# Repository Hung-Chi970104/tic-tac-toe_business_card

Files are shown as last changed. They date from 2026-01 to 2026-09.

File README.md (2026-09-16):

# Tic-Tac-Toe Business Card

**A playable RP2040 business card with a printed NFC antenna and a minimax computer opponent.**

[PCB layout](#pcb-layout) · [NFC design](#passive-nfc-and-antenna) · [Demos](#see-it-work) · [Schematic](#schematic) · [Design files](#design-files)

## PCB layout

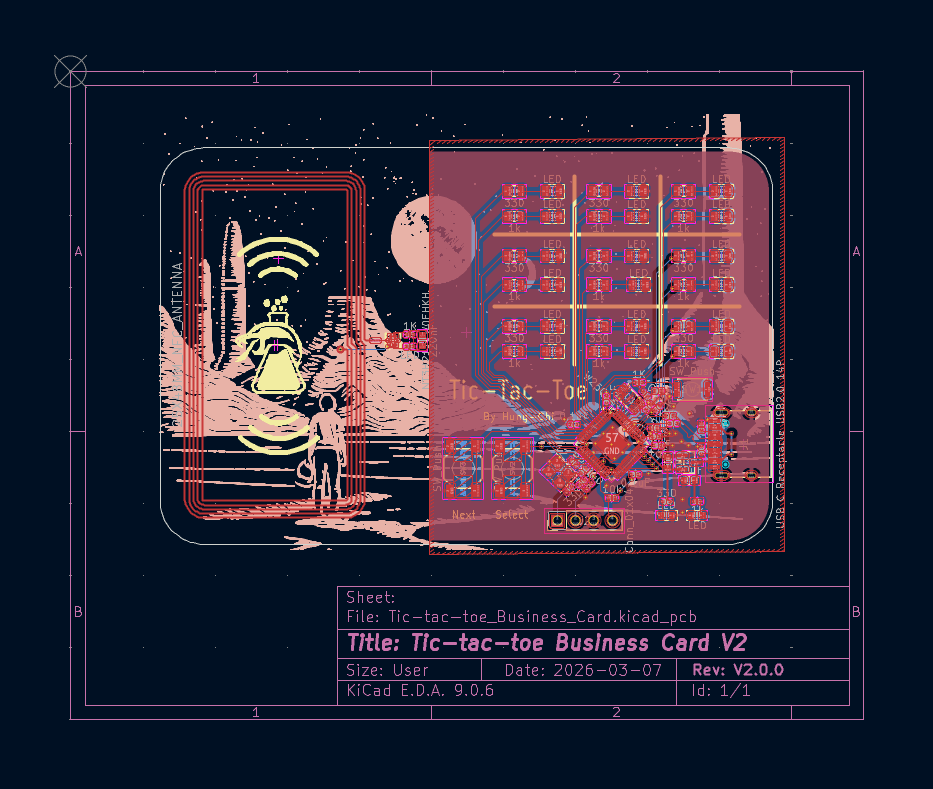
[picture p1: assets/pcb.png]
Routed business-card PCB showing the copper NFC coil, nine game cells and RP2040 circuitry


The layout combines a large copper-coil NFC antenna with the game interface and embedded electronics. The **18 game LEDs form nine dual-colour cells**, giving each player one indicator per square; Next and Select buttons provide the controls.

## What I built

- Designed the RP2040 board, LED interface, USB-C connection and passive NFC circuit.
- Integrated a **25 × 48 mm PCB copper-coil antenna** with an **NT3H2111 NFC tag**.
- Implemented two-player gameplay and a **minimax opponent with alpha-beta pruning**, which skips search branches that cannot improve the chosen move.
- Completed two PCB revisions, resolving the initial NFC fault and demonstrating both gameplay and tap-to-open linking.

## Passive NFC and antenna

The coil is part of the PCB copper, connected to the NFC tag's antenna terminals. A compatible phone supplies the field needed for passive **13.56 MHz** NFC reading, so the portfolio link can be read **without USB power**. Gameplay uses the powered RP2040 and LED circuit.

The grid uses 18 LEDs; three additional indicators sit outside the nine game cells.

## See it work

| Demonstration | Watch |
|---|---|
| Two-player game | [Gameplay video](https://youtube.com/shorts/xTpW4rk7Zjw) |
| Computer opponent | [Minimax gameplay](https://youtu.be/wkJYNbXEyfI) |
| Passive NFC | [Phone tap → portfolio link](https://youtube.com/shorts/Xky8sBx_JWE) |

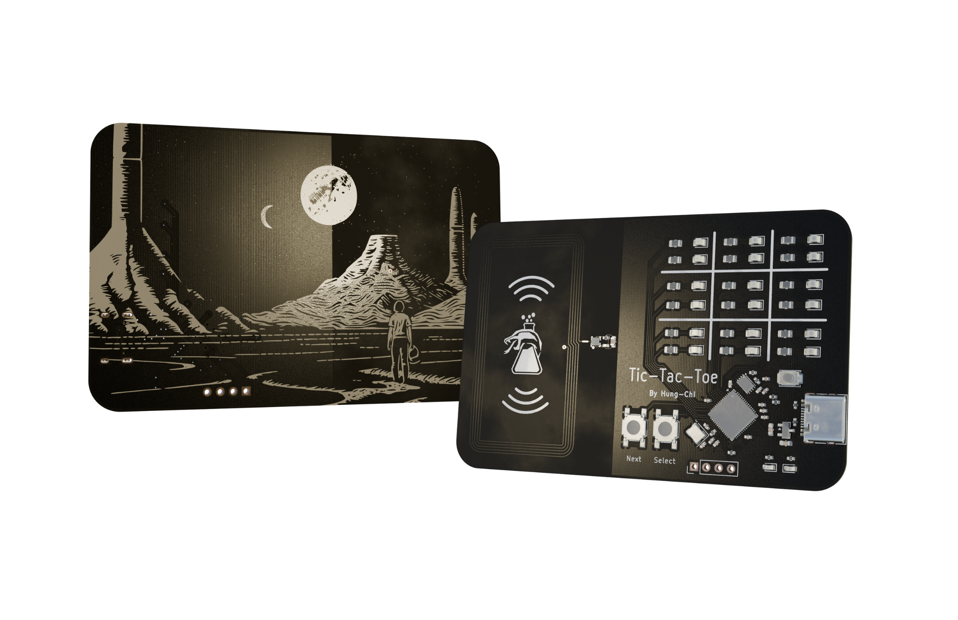
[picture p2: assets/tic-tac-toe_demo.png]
Original project demonstration image (https://youtu.be/wkJYNbXEyfI)


## Schematic

[Full-resolution schematic](assets/schematic.svg) · [KiCad schematic](Tic-tac-toe_Business_Card.kicad_sch)

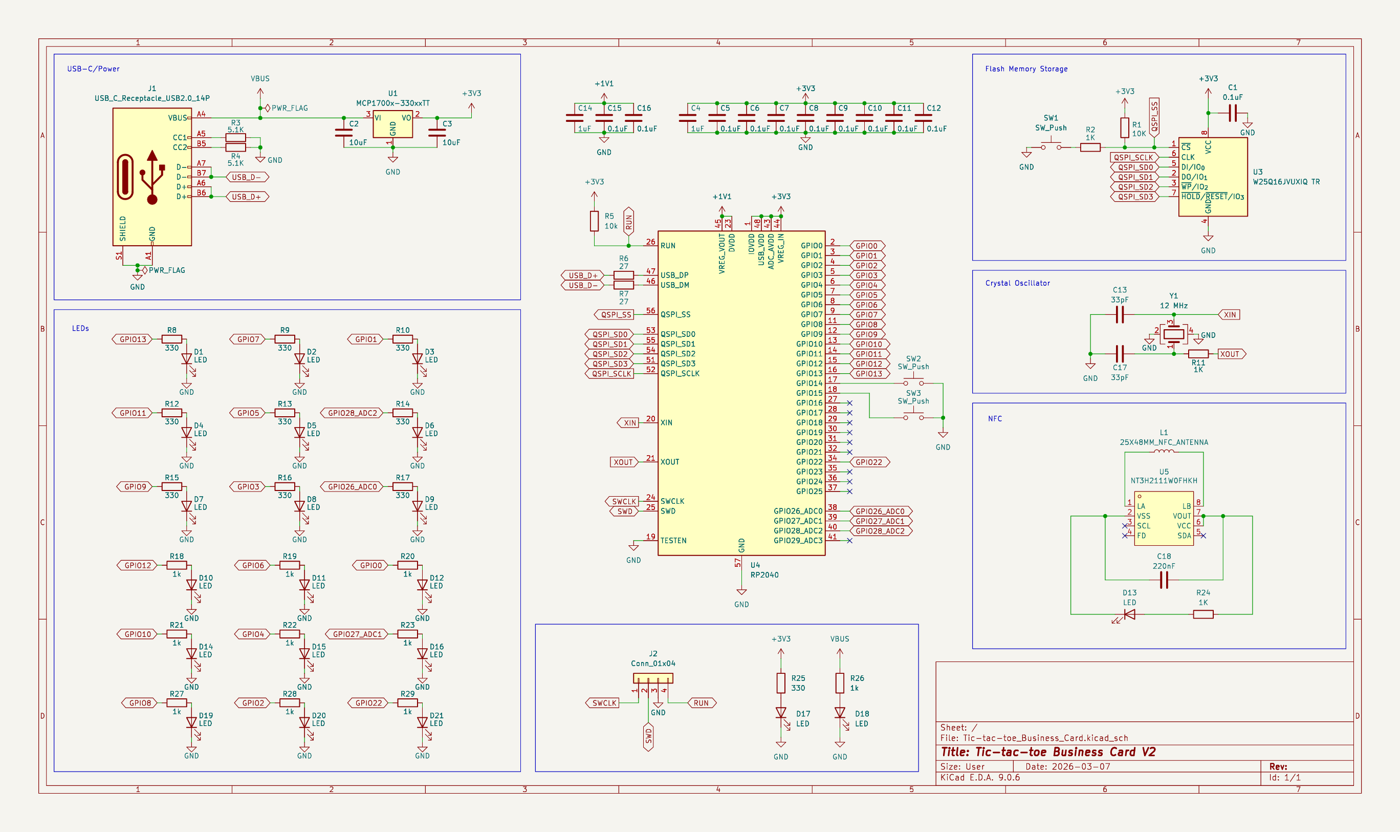
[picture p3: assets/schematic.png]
Schematic of the RP2040, game LEDs, controls and NFC circuitry


## 3D views

Original board renders:

| Front | Back |
|---|---|
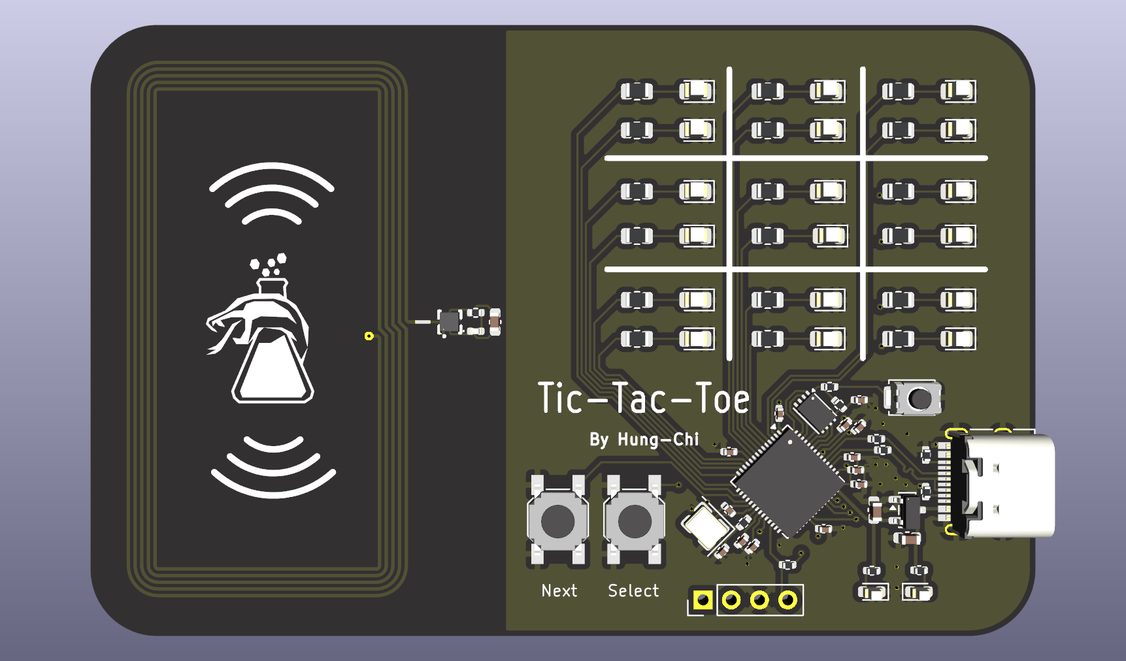
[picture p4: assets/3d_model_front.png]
Original front 3D view
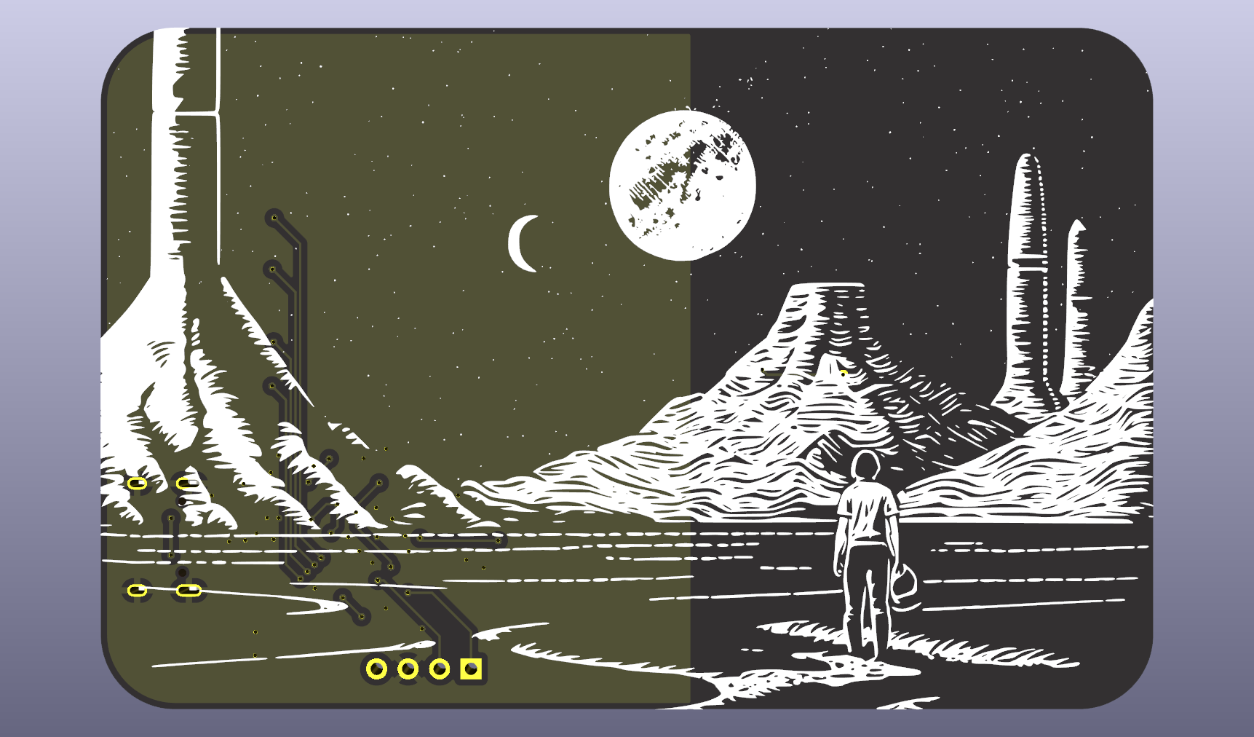
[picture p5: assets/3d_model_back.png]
Original back 3D view
|  |  |

## Design files

| Resource | Link |
|---|---|
| KiCad project | [Project file](Tic-tac-toe_Business_Card.kicad_pro) |
| Routed board | [PCB source](Tic-tac-toe_Business_Card.kicad_pcb) |
| Copper layers | [Front](assets/Tic-tac-toe_Business_Card-F_Cu.svg) · [Back](assets/Tic-tac-toe_Business_Card-B_Cu.svg) |
| NFC footprint | [25 × 48 mm antenna source](lib/NFC_Tic_Tac_Toe.pretty/25X48MM_NFC_ANTENNA.kicad_mod) |
| Manufacturing exports | [Production files](production/) |

The repository contains the hardware design and demonstration assets. The gameplay implementation is demonstrated in the videos; a complete firmware release is not currently included here.

Designed and built by Hung-Chi Wang.

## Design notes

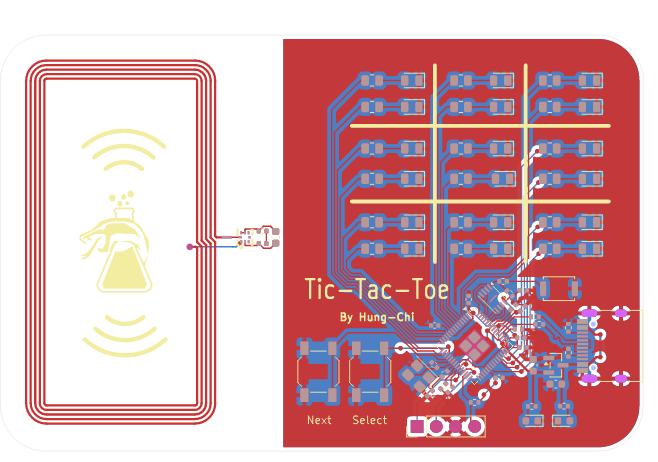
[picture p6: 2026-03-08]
assets/Tic-tac-toe_Business_Card-B_Cu.png

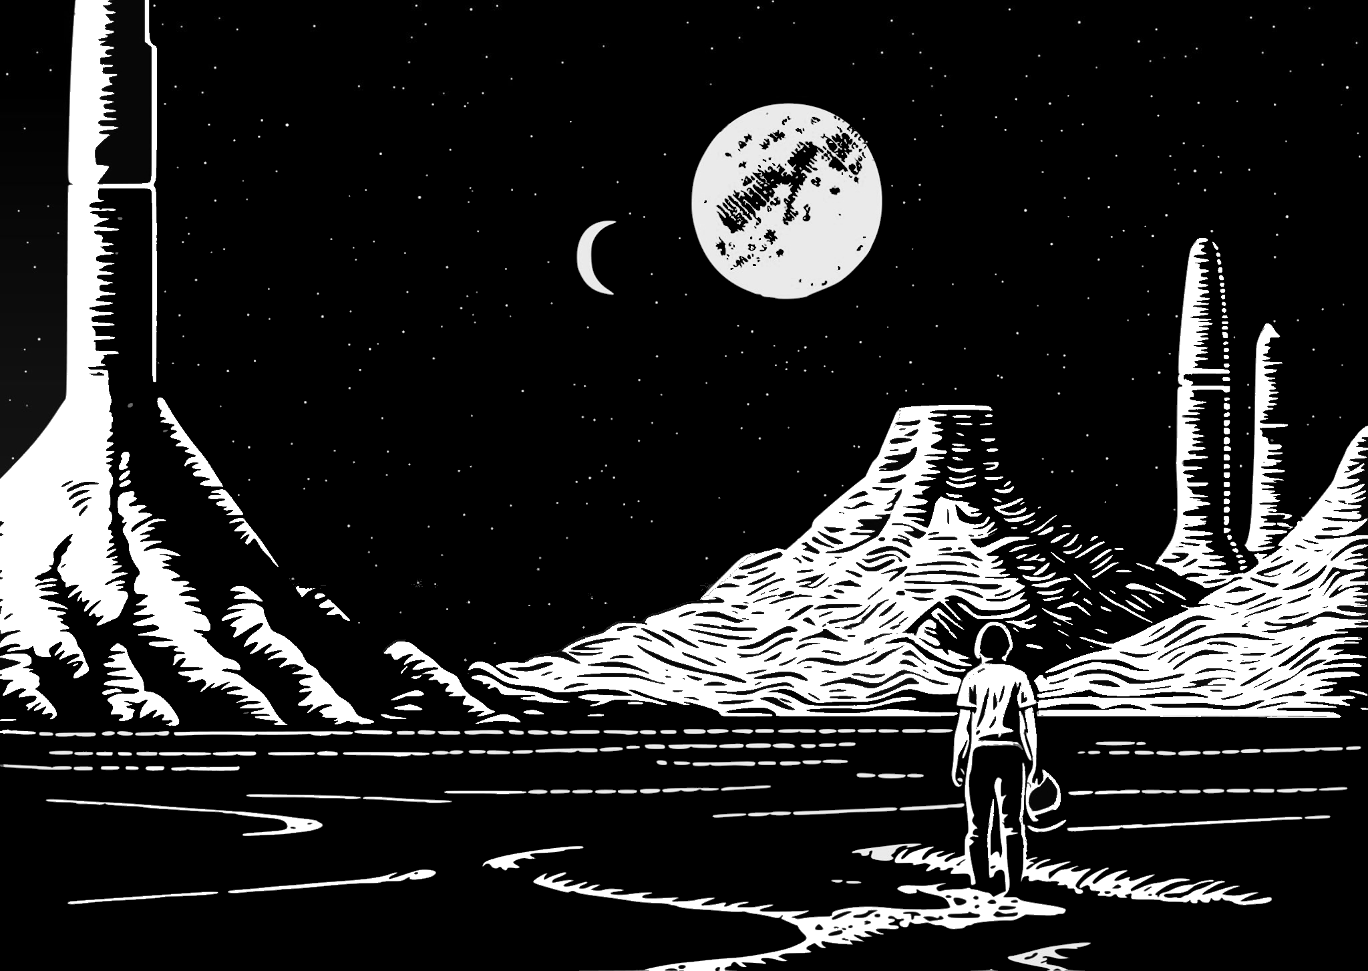
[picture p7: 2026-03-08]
assets/back-image.png

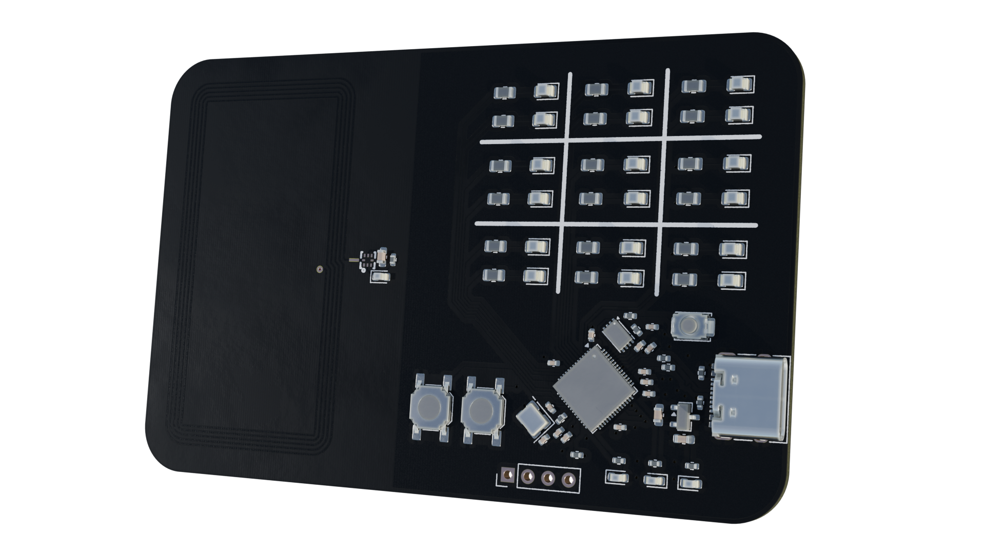
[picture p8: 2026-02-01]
assets/RP2040-tic-tac-toe.png

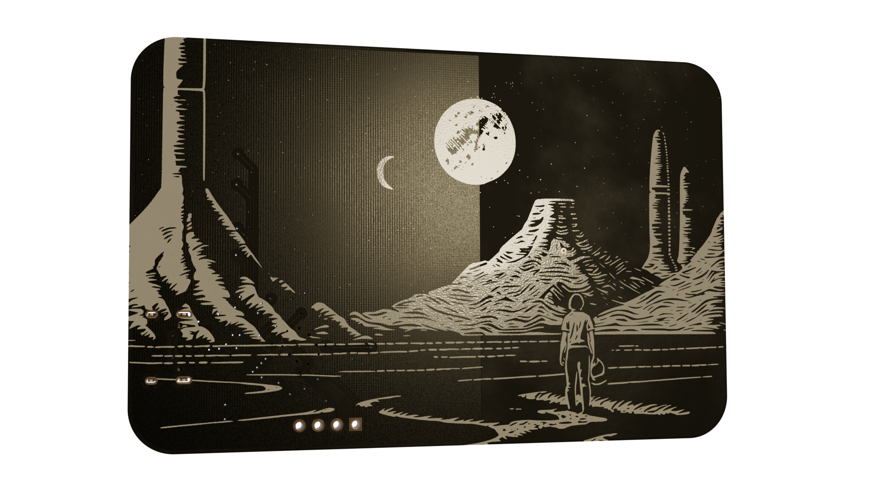
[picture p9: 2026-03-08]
assets/tic-tac-toe_back.png

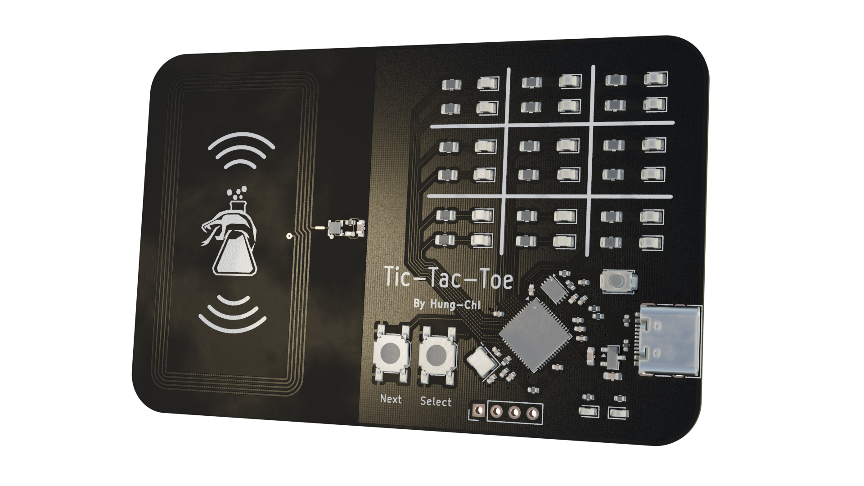
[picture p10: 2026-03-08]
assets/tic_tac_toe_front.png

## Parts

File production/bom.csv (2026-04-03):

Designator | Footprint | Quantity | Value | LCSC Part #
C1, C11, C12, C15, C16, C6, C7, C8, C9 | 0402 | 9 | 0.1uF
C13, C17 | 0402 | 2 | 15pF
C14, C4 | 0402 | 2 | 1uF
C18 | 0603 | 1 | 220nF
C2, C3 | 0603 | 2 | 10uF
D1, D10, D11, D12, D14, D15, D16, D19, D2, D20, D21, D3, D4, D5, D6, D7, D8, D9 | 0805 | 18 | LED
D13 | 0402 | 1 | LED
D17, D18 | 0603 | 2 | LED
J1 | USB_C_Receptacle_HRO_TYPE-C-31-M-12 | 1 | USB_C_Receptacle_USB2.0_14P
J2 | PinHeader_1x04_P2.54mm_Vertical | 1 | Conn_01x04
L1 | 25X48MM_NFC_ANTENNA | 1 | 25X48MM_NFC_ANTENNA
R1, R5 | 0402 | 2 | 10K
R10, R12, R13, R14, R15, R16, R17, R8, R9 | 0805 | 9 | 330
R11, R2, R26, R24 | 0402 | 4 | 1K
R18, R19, R20, R21, R22, R23, R27, R28, R29 | 0805 | 9 | 1k
R25 | 0402 | 1 | 330
R3, R4 | 0402 | 2 | 5.1K
R6, R7 | 0402 | 2 | 27
SW1 | SW_Push_SPST_NO_Alps_SKRK | 1 | SW_Push
SW2, SW3 | SW_SPST_SKQG_WithoutStem | 2 | SW_Push
U1 | SOT-23 | 1 | MCP1700x-330xxTT
U3 | Winbond_USON-8-1EP_3x2mm_P0.5mm_EP0.2x1.6mm | 1 | W25Q16JVUXIQ TR
U4 | QFN-56-1EP_7x7mm_P0.4mm_EP3.2x3.2mm | 1 | RP2040
U5 | XQFN-8_L1.6-W1.6-P0.50-BL_NT3H2111W0FHKH | 1 | NT3H2111W0FHKH | C710403
Y1 | Crystal_SMD_3225-4Pin_3.2x2.5mm | 1 | 12 MHz

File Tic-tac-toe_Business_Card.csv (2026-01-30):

Reference | Qty | Value | DNP | Exclude from BOM | Exclude from Board | Footprint | Datasheet
C1,C2 | 2 | 10uF |  |  |  | Capacitor_SMD:C_0603_1608Metric | ~
C3,C5,C6,C8,C9,C10,C11,C12,C13,C14,C15 | 11 | 0.1uF |  |  |  | Capacitor_SMD:C_0402_1005Metric | ~
C4,C7 | 2 | 1uF |  |  |  | Capacitor_SMD:C_0402_1005Metric | ~
C16,C17 | 2 | 33pF |  |  |  | Capacitor_SMD:C_0402_1005Metric | ~
C18 | 1 | 220nF |  |  |  | Capacitor_SMD:C_0603_1608Metric | ~
D1,D2,D3,D13 | 4 | LED |  |  |  | LED_SMD:LED_0603_1608Metric | ~
D4,D5,D6,D7,D8,D9,D10,D11,D12,D22,D23,D24,D25,D26,D27,D28,D29,D30 | 18 | LED |  |  |  | LED_SMD:LED_0805_2012Metric | ~
J1 | 1 | USB_C_Receptacle_USB2.0_14P |  |  |  | Connector_USB:USB_C_Receptacle_HRO_TYPE-C-31-M-12 | https://www.usb.org/sites/default/files/documents/usb_type-c.zip
J2 | 1 | Conn_01x04 |  |  |  | Connector_PinHeader_2.54mm:PinHeader_1x04_P2.54mm_Vertical | ~
L1 | 1 | 25X48MM_NFC_ANTENNA |  |  |  | NFC_Tic_Tac_Toe:25X48MM_NFC_ANTENNA | ~
R1,R2 | 2 | 5.1K |  |  |  | Resistor_SMD:R_0402_1005Metric | ~
R3 | 1 | 10K |  |  |  | Resistor_SMD:R_0402_1005Metric | ~
R4,R8 | 2 | 1K |  |  |  | Resistor_SMD:R_0402_1005Metric | ~
R5 | 1 | 10k |  |  |  | Resistor_SMD:R_0402_1005Metric | ~
R6,R7 | 2 | 27 |  |  |  | Resistor_SMD:R_0402_1005Metric | ~
R9,R10,R21 | 3 | 330 |  |  |  | Resistor_SMD:R_0402_1005Metric | ~
R11 | 1 | 1k |  |  |  | Resistor_SMD:R_0402_1005Metric | ~
R12,R13,R14,R15,R16,R17,R18,R19,R20 | 9 | 330 |  |  |  | Resistor_SMD:R_0805_2012Metric | ~
R30,R31,R32,R33,R34,R35,R36,R37,R38 | 9 | 1k |  |  |  | Resistor_SMD:R_0805_2012Metric | ~
SW1 | 1 | SW_Push |  |  |  | Button_Switch_SMD:SW_Push_SPST_NO_Alps_SKRK | ~
SW2,SW3 | 2 | SW_Push |  |  |  | Button_Switch_SMD:SW_SPST_SKQG_WithoutStem | ~
U1 | 1 | MCP1700x-330xxTT |  |  |  | Package_TO_SOT_SMD:SOT-23 | http://ww1.microchip.com/downloads/en/DeviceDoc/20001826D.pdf
U2 | 1 | NT3H2111W0FHKH |  |  |  | NFC_Tic_Tac_Toe:XQFN-8_L1.6-W1.6-P0.50-BL_NT3H2111W0FHKH
U3 | 1 | RP2040 |  |  |  | Package_DFN_QFN:QFN-56-1EP_7x7mm_P0.4mm_EP3.2x3.2mm | https://datasheets.raspberrypi.com/rp2040/rp2040-datasheet.pdf
U4 | 1 | W25Q16JVUXIQ TR |  |  |  | Package_SON:Winbond_USON-8-1EP_3x2mm_P0.5mm_EP0.2x1.6mm | https://www.winbond.com/resource-files/w25q128jv_dtr%20revc%2003272018%20plus.pdf
Y1 | 1 | 12 MHz |  |  |  | Crystal:Crystal_SMD_3225-4Pin_3.2x2.5mm | ~

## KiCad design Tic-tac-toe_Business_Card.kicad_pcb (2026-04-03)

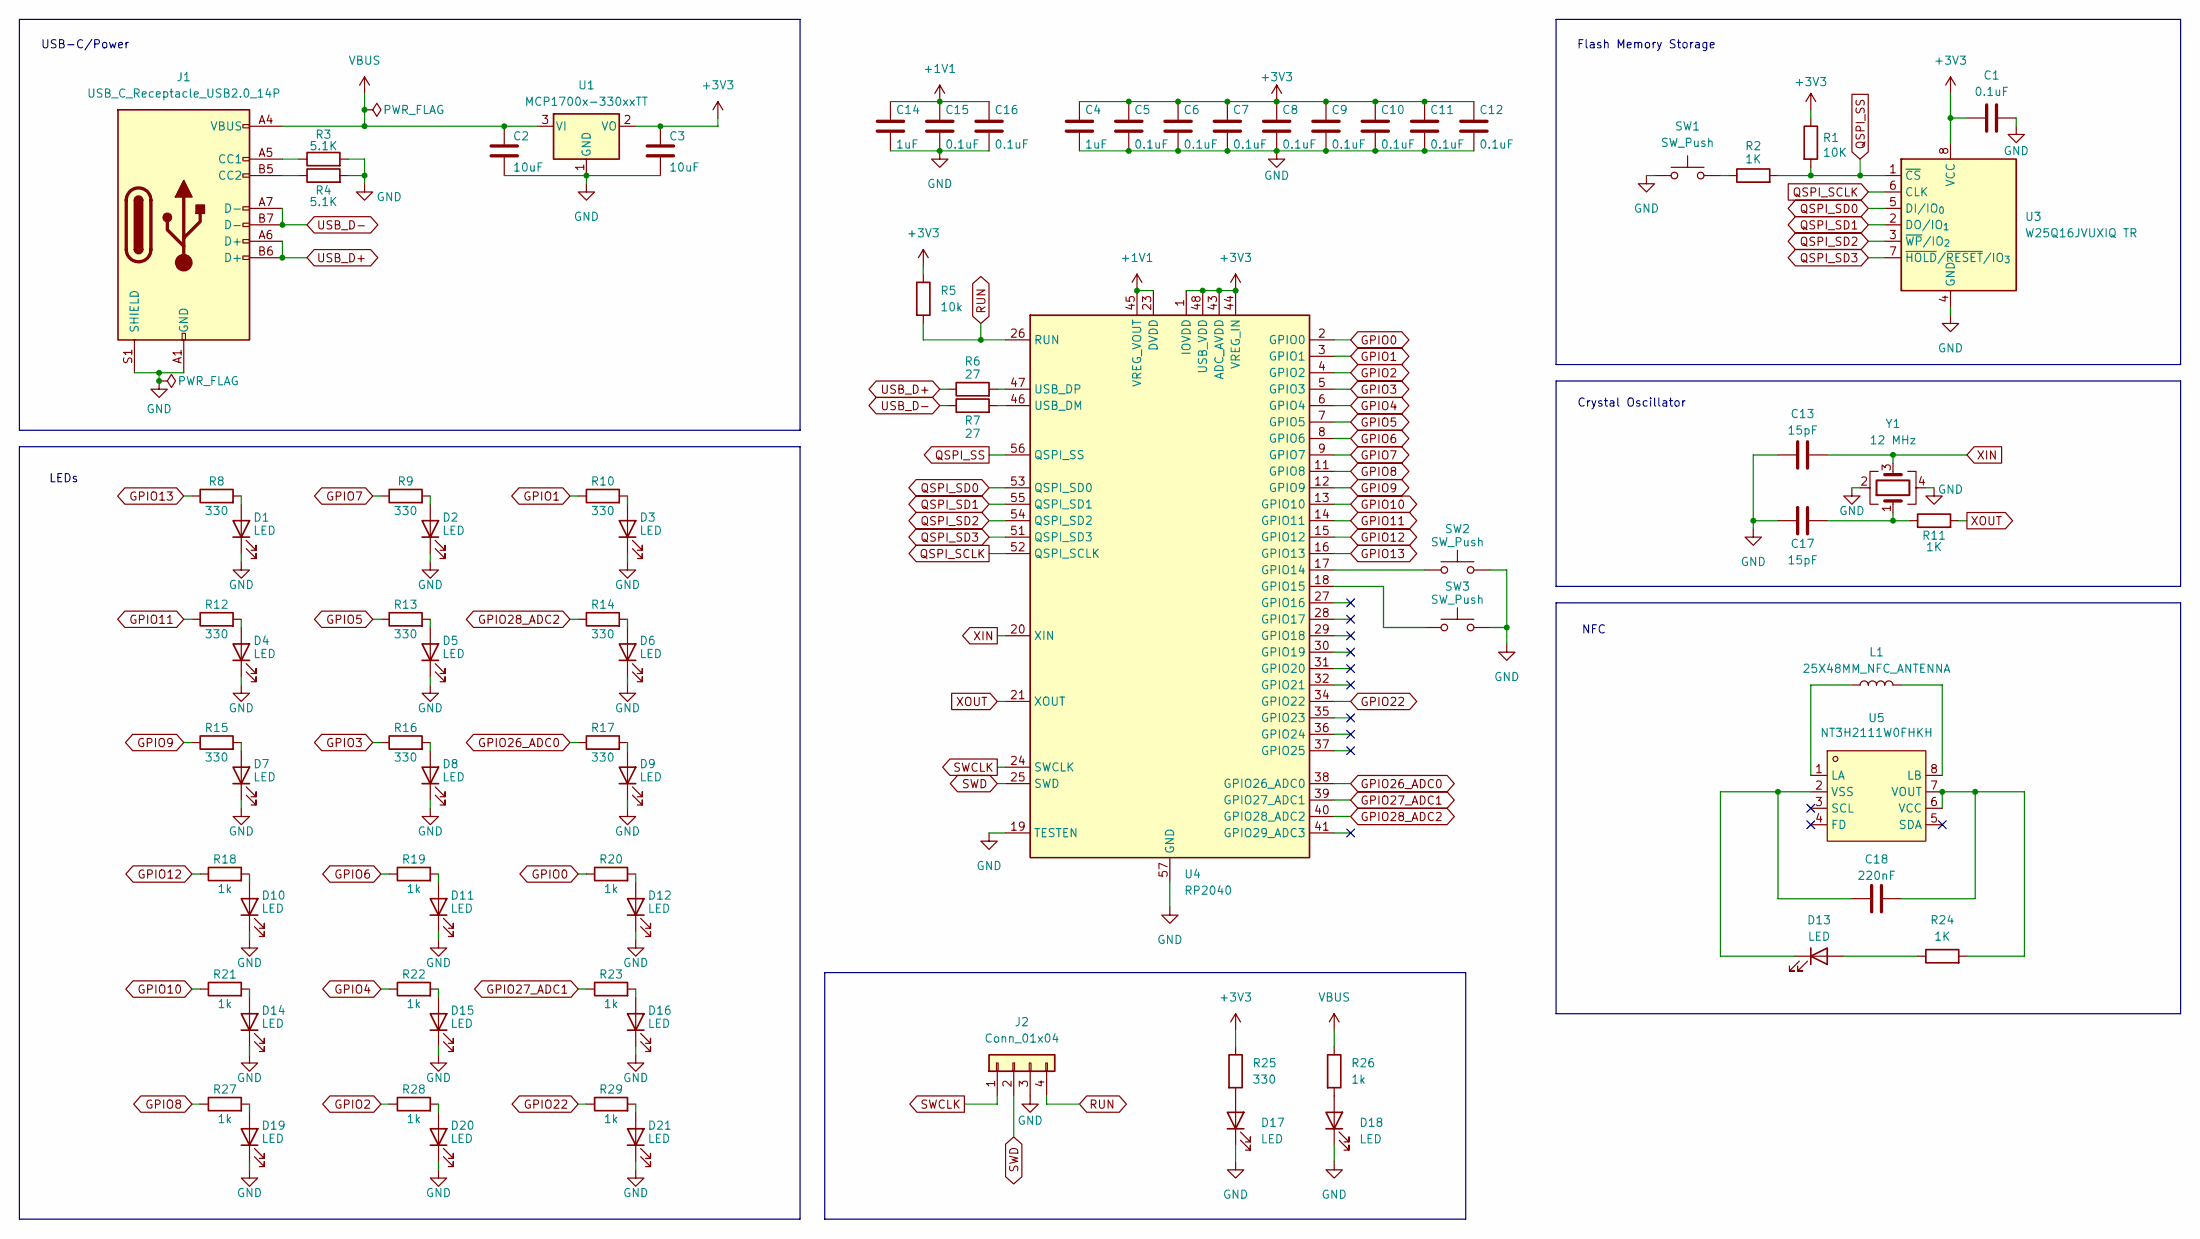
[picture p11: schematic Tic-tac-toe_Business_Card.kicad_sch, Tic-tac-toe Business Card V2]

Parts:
C1, C5, C6, C7, C8, C9, C10, C11, C12, C15, C16: 0.1uF; C_0402_1005Metric
C2, C3: 10uF; C_0603_1608Metric
C4, C14: 1uF; C_0402_1005Metric
C13, C17: 15pF; C_0402_1005Metric
C18: 220nF; C_0603_1608Metric
D1, D2, D3, D4, D5, D6, D7, D8, D9, D10, D11, D12, D14, D15, D16, D19, D20, D21: LED; LED_0805_2012Metric
D13: LED; LED_0402_1005Metric
D17, D18: LED; LED_0603_1608Metric
J1: USB_C_Receptacle_USB2.0_14P; USB_C_Receptacle_HRO_TYPE-C-31-M-12
J2: Conn_01x04; PinHeader_1x04_P2.54mm_Vertical
L1: 25X48MM_NFC_ANTENNA
R1: 10K; R_0402_1005Metric
R2, R11: 1K; R_0402_1005Metric
R3, R4: 5.1K; R_0402_1005Metric
R5: 10k; R_0402_1005Metric
R6, R7: 27; R_0402_1005Metric
R8, R9, R10, R12, R13, R14, R15, R16, R17: 330; R_0805_2012Metric
R18, R19, R20, R21, R22, R23, R27, R28, R29: 1k; R_0805_2012Metric
R24: 1K; R_0402_1005Metric; LCSC C23182
R25: 330; R_0402_1005Metric
R26: 1k; R_0402_1005Metric
SW1: SW_Push; SW_Push_SPST_NO_Alps_SKRK
SW2, SW3: SW_Push; SW_SPST_SKQG_WithoutStem
U1: MCP1700x-330xxTT; SOT-23
U3: W25Q16JVUXIQ TR; Winbond_USON-8-1EP_3x2mm_P0.5mm_EP0.2x1.6mm
U4: RP2040; QFN-56-1EP_7x7mm_P0.4mm_EP3.2x3.2mm
U5: NT3H2111W0FHKH; XQFN-8_L1.6-W1.6-P0.50-BL_NT3H2111W0FHKH; LCSC C710403
Y1: 12 MHz; Crystal_SMD_3225-4Pin_3.2x2.5mm

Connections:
+1V1: C14.1, C15.1, C16.1, U4.23 (DVDD), U4.45 (VREG_VOUT), U4.50 (DVDD)
+3V3: C1.1, C3.1, C4.1, C5.1, C6.1, C7.1, C8.1, C9.1, C10.1, C11.1, C12.1, R1.1, R5.1, R25.1, U1.2 (VO), U3.8 (VCC), U4.1 (IOVDD), U4.10 (IOVDD), U4.22 (IOVDD), U4.33 (IOVDD), U4.42 (IOVDD), U4.43 (ADC_AVDD), U4.44 (VREG_IN), U4.48 (USB_VDD), U4.49 (IOVDD)
GND: C1.2, C2.2, C3.2, C4.2, C5.2, C6.2, C7.2, C8.2, C9.2, C10.2, C11.2, C12.2, C13.1, C14.2, C15.2, C16.2, C17.1, D1.1 (K), D2.1 (K), D3.1 (K), D4.1 (K), D5.1 (K), D6.1 (K), D7.1 (K), D8.1 (K), D9.1 (K), D10.1 (K), D11.1 (K), D12.1 (K), D14.1 (K), D15.1 (K), D16.1 (K), D17.1 (K), D18.1 (K), D19.1 (K), D20.1 (K), D21.1 (K), J1.A1 (GND), J1.A12 (GND), J1.B1 (GND), J1.B12 (GND), J1.S1 (SHIELD), J2.3, R3.2, R4.2, SW1.1, SW2.2, SW3.2, U1.1 (GND), U3.4 (GND), U4.19 (TESTEN), U4.57 (GND), Y1.2, Y1.4
GPIO0: R20.1, U4.2 (GPIO0)
GPIO1: R10.1, U4.3 (GPIO1)
GPIO2: R28.1, U4.4 (GPIO2)
GPIO3: R16.1, U4.5 (GPIO3)
GPIO4: R22.1, U4.6 (GPIO4)
GPIO5: R13.1, U4.7 (GPIO5)
GPIO6: R19.1, U4.8 (GPIO6)
GPIO7: R9.1, U4.9 (GPIO7)
GPIO8: R27.1, U4.11 (GPIO8)
GPIO9: R15.1, U4.12 (GPIO9)
GPIO10: R21.1, U4.13 (GPIO10)
GPIO11: R12.1, U4.14 (GPIO11)
GPIO12: R18.1, U4.15 (GPIO12)
GPIO13: R8.1, U4.16 (GPIO13)
GPIO22: R29.1, U4.34 (GPIO22)
GPIO26_ADC0: R17.1, U4.38 (GPIO26_ADC0)
GPIO27_ADC1: R23.1, U4.39 (GPIO27_ADC1)
GPIO28_ADC2: R14.1, U4.40 (GPIO28_ADC2)
unnamed: C17.2, R11.1, Y1.1
unnamed: D1.2 (A), R8.2
unnamed: D2.2 (A), R9.2
unnamed: D3.2 (A), R10.2
unnamed: D4.2 (A), R12.2
unnamed: D5.2 (A), R13.2
unnamed: D6.2 (A), R14.2
unnamed: D7.2 (A), R15.2
unnamed: D8.2 (A), R16.2
unnamed: D9.2 (A), R17.2
unnamed: D10.2 (A), R18.2
unnamed: D11.2 (A), R19.2
unnamed: D12.2 (A), R20.2
unnamed: D13.2 (A), R24.1
unnamed: C18.1, D13.1 (K), U5.2 (VSS)
unnamed: D14.2 (A), R21.2
unnamed: D15.2 (A), R22.2
unnamed: D16.2 (A), R23.2
unnamed: D17.2 (A), R25.2
unnamed: D18.2 (A), R26.2
unnamed: D19.2 (A), R27.2
unnamed: D20.2 (A), R28.2
unnamed: D21.2 (A), R29.2
unnamed: J1.A5 (CC1), R3.1
unnamed: J1.B5 (CC2), R4.1
unnamed: R2.1, SW1.2
unnamed: SW2.1, U4.17 (GPIO14)
unnamed: SW3.1, U4.18 (GPIO15)
unnamed: R7.2, U4.46 (USB_DM)
unnamed: R6.2, U4.47 (USB_DP)
unnamed: L1.1, U5.1 (LA)
unnamed: L1.2, U5.8 (LB)
unnamed: C18.2, R24.2, U5.6 (VCC), U5.7 (VOUT)
QSPI_SCLK: U3.6 (CLK), U4.52 (QSPI_SCLK)
QSPI_SD0: U3.5 (DI/IO_{0}), U4.53 (QSPI_SD0)
QSPI_SD1: U3.2 (DO/IO_{1}), U4.55 (QSPI_SD1)
QSPI_SD2: U3.3 (~WP/IO_{2}), U4.54 (QSPI_SD2)
QSPI_SD3: U3.7 (~HOLD/~RESET/IO_{3}), U4.51 (QSPI_SD3)
QSPI_SS: R1.2, R2.2, U3.1 (~CS), U4.56 (QSPI_SS)
RUN: J2.4, R5.2, U4.26 (RUN)
SWCLK: J2.1, U4.24 (SWCLK)
SWD: J2.2, U4.25 (SWD)
USB_D+: J1.A6 (D+), J1.B6 (D+), R6.1
USB_D-: J1.A7 (D-), J1.B7 (D-), R7.1
VBUS: C2.1, J1.A4 (VBUS), J1.A9 (VBUS), J1.B4 (VBUS), J1.B9 (VBUS), R26.1, U1.3 (VI)
XIN: C13.2, U4.20 (XIN), Y1.3
XOUT: R11.2, U4.21 (XOUT)

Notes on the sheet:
NFC
Crystal Oscillator
LEDs
USB-C/Power
Flash Memory Storage

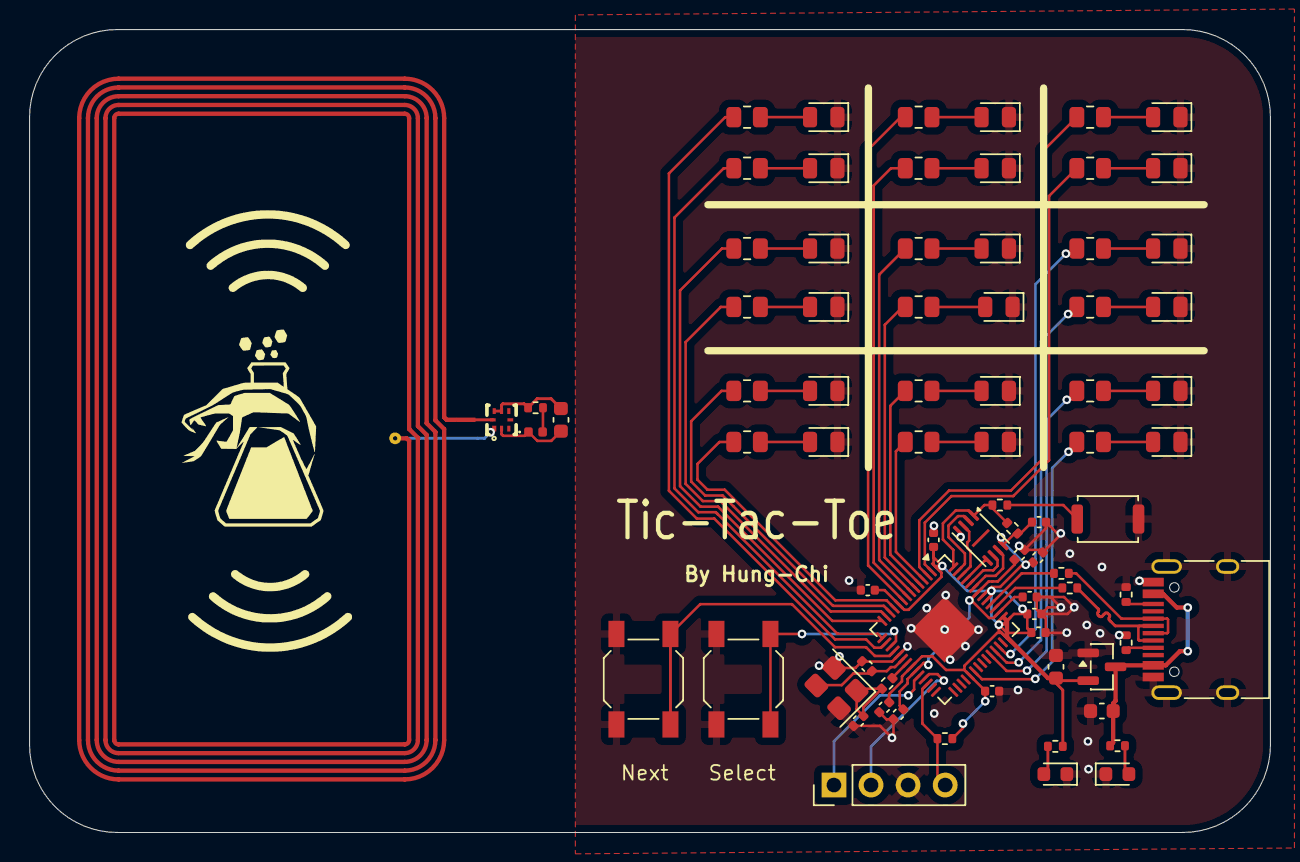
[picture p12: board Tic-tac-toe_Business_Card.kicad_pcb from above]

Board: 2 copper layers, 85.0 x 55.0 mm, 77 parts (0 on the bottom side), 68 nets.

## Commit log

2026-04-03 Update Repo
    [Tic-tac-toe_Business_Card.kicad_pcb, Tic-tac-toe_Business_Card.kicad_sch, bom.csv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]
2026-09-16 Present routed PCB, engineering contributions and demonstrations clearly
